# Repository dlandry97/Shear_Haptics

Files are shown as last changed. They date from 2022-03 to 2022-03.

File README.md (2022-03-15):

# Shear Haptics
The two main portions of this project include the design the mechanical structure of the device, and the integration of the haptic feedback with a virtual environment.

## How to use
1. This project uses:
    a. Unity Hub with Unity Editor run on Windows
    b. Oculus Rift with Rift Touch controllers
    c. Arduino Uno and Adafruit motorshieldv2
    d. prototype assembled with 3d printed parts(stls in models repo), servo motors, shafts, bearings, and timing belt(Links to amazon pages to non printed materials at bottom).
2. You will first need to download the arduino code from the arduino folder of the repo, and use the arduino IDE to upload it to an 'arduino uno' with a 'adafruit shieldv2'
3. You will also need the devices 

## Design
My general goal for the design was to create a shear movment about the controller grip with minimal actuators and a comfortable form as a handheld device. To achieve the linear motion of the grips, I considered many actuation schemes such as; linear actuators, worm gears, gears, belt drives. I decided to use a timing belt system actuated by a single high torque servo motor. The belt driven system gives the advantage of displacing the motor location away from the handle while still achieving strong linear force through the grips. The timing belt attaches to a set of carts guided by steel shaft rails. These shafts would function as a skeletal structure of the device as well as guide the grips in a linear path up and down the device. The second prototype increases efficiency and confort by slimming down the size of the mechanism while increasing the size of the grips.

prototypes

## Actuation
The actuation of the device is provided by a single 35kg/cm servo motor controlled by an arduino uno microcontroller. The servo drives a timing belt that attaches to and drives the grips. Each grip is designed to have a -10mm to 10mm travel range. I mounted and tested othe motor types. Using a stepper motor provided a decent amount of speed to the grip movement, but did not provide nearly enough torque to create a haptic feel. A brushed DC motor was tested and proved that it could provide torque, but did not have a sufficient ammount of speed or control for rapid testing. I added a belt gear drive to the servo system in attempt to increase its speed but keep a decent amount of torque, but the servo would stall from resistance torque from the grip.

## Interfacing
I used Unity game enigne to create a VR demo environemnt to integrate with the device. I'm using serial communication to read and write signals from Unity to the arduino to sync up to impacts in VR to the haptic feedback of the controller. I use Unity to design a VR sword that I can track the velocity data and collision status to determine the type of collision and send the appropriate status flags to the arduino to actuate the motor in the controller.

VR_Demo

### Material links
To assemble the devices, you will need the materials below or equivalent.

4mm Steel shafts: https://www.amazon.com/uxcell-Lathe-Round-Solid-Length/dp/B07KT3TT7P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

5mm shafts: https://www.amazon.com/uxcell-Stainless-Support-Fasten-Elements/dp/B07MB8QV7J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

Timing belt: https://www.amazon.com/KeeYees-Timing-Tensioner-Torsion-Printer/dp/B07JKT5BZQ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

Arduino: https://www.amazon.com/Arduino-A000066-ARDUINO-UNO-R3/dp/B008GRTSV6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

motor shield: https://www.amazon.com/Adafruit-Motor-Stepper-Shield-Arduino/dp/B00PUTH3B0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

servo shaft connector: https://www.amazon.com/Seamuing-Aluminum-Futaba-Mechanical-Helicopter/dp/B07D56FVK5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

5mm shaft connector: https://www.amazon.com/Coupling-Connector-Coupler-Accessory-Fittings/dp/B08334MFVT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

5mm bearings: https://www.amazon.com/F695-2RS-Bearing-5x13x4mm-Miniature-Bearings/dp/B07VMJLXLH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

Heat Inserts: https://www.amazon.com/F695-2RS-Bearing-5x13x4mm-Miniature-Bearings/dp/B07VMJLXLH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

Servo Motor: https://www.amazon.com/ZOSKAY-Coreless-Digital-Stainless-arduino/dp/B07S9XZYN2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

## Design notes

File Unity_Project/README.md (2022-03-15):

# Unity Project instructions
To open this project, you will need Unity Hub on Windows and an Oculus Rift Headset with the touch controllers. 
1. Download the project file and put it somewhere it can stay.
2. Open the Unity Hub and got to projects. At the top right select 'add project' and navigate to the project location.
3. Once you see the project in the Hub project menu, double click it and choose any Editior version to run it on. 
    There may be a few popups reguarding editor versions, you can chose anything.
    You may be prompted about the STEAMVR plugin and asekd to '*RESTART', Do not restart, just keep the version and select the other button.
4. The project will import and redownload all the library files that were deleted to save space for importing the project.
5. Once you get into the editor, at the bottor under 'assets', select 'My folder' and open the scene called 'This is the scene'.
6. The scene may have a few errors due to missing assets that were removed because they were purchased assets.
7. To run the demo as is, you may need an oculus rift headset and rift touch controllers for the current drivers to automatically recognise the setup.
8. You may plug in your arduino with the correct scripts already loaded. Take not of the COM port it is currently using.
9. In the scene, you may need to select the 'SerialController' object and change the 'serial COM port' to match the port of the arduino.
10. Press the 'play' button at the top of the editor to start the demo and put on your VR headset.
11. Grab the virtual Katanas and have fun with the demo.

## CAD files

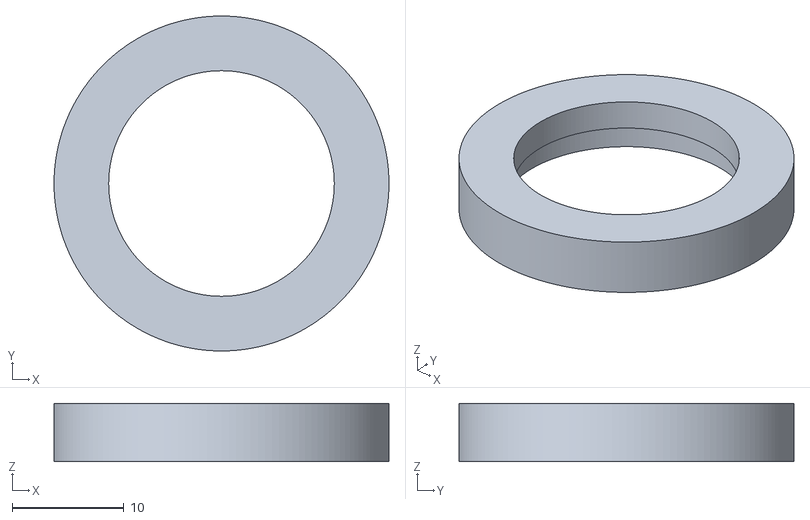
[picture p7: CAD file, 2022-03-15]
models/misc/shaft join.stl
30.0 x 30.0 x 5.20

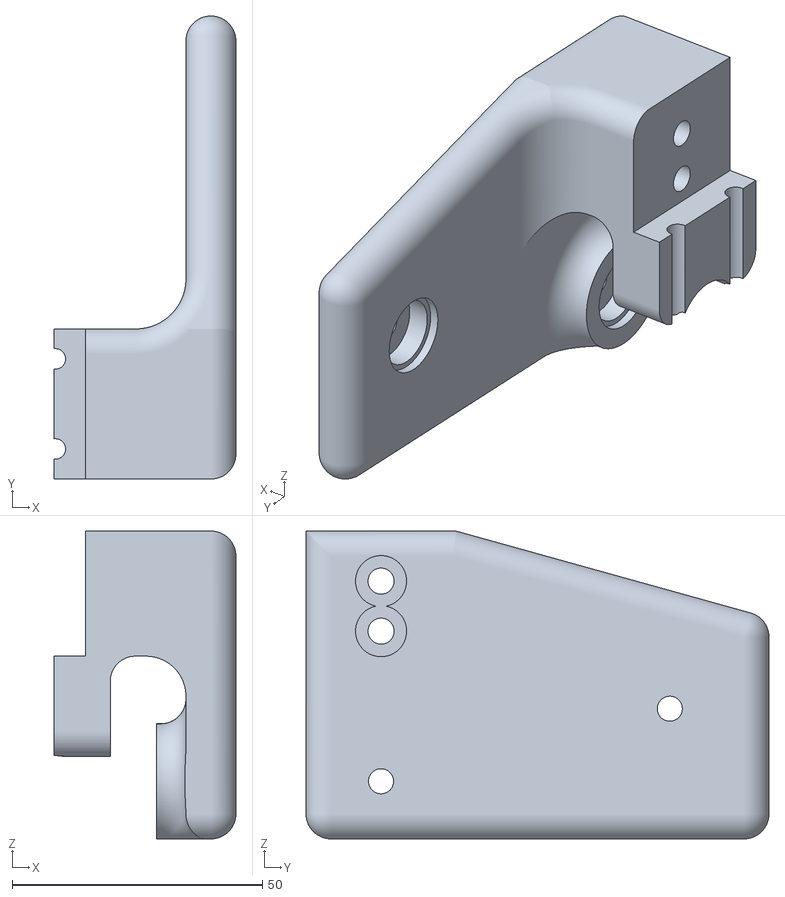
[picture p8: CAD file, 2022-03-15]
models/mk3/gearbox v4.stl
36.3 x 92.5 x 61.5

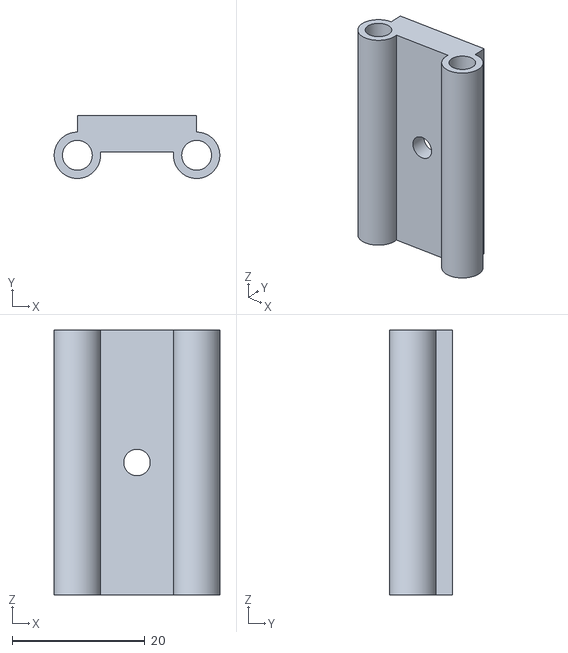
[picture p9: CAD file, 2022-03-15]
models/misc/rail_cartv3.stl
25.0 x 9.50 x 40.0

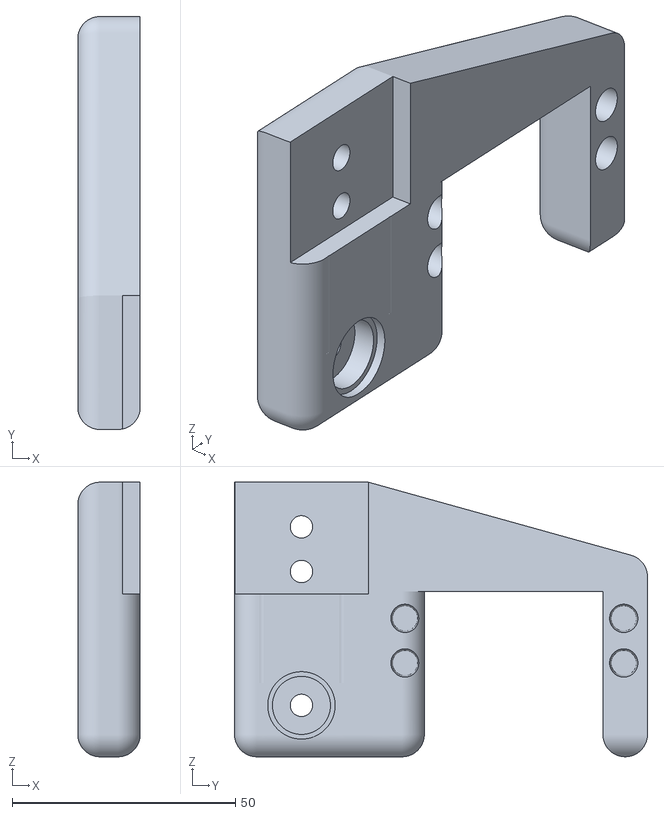
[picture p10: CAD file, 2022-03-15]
models/mk3/motor mount v4.stl
14.0 x 92.5 x 61.5

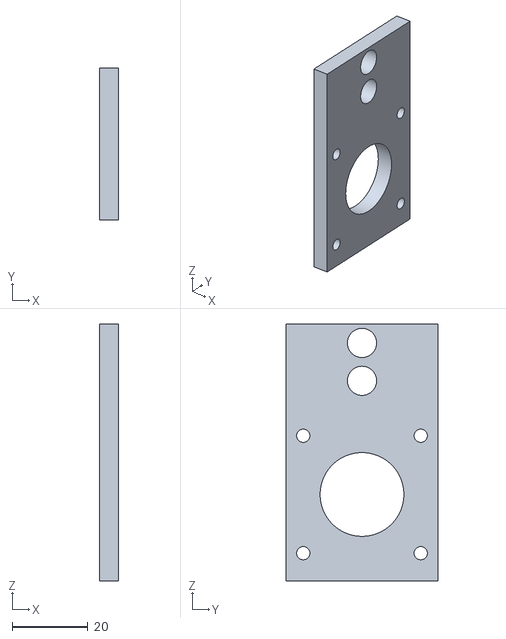
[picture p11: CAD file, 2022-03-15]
models/misc/stepper mount.stl
5.00 x 40.0 x 67.8

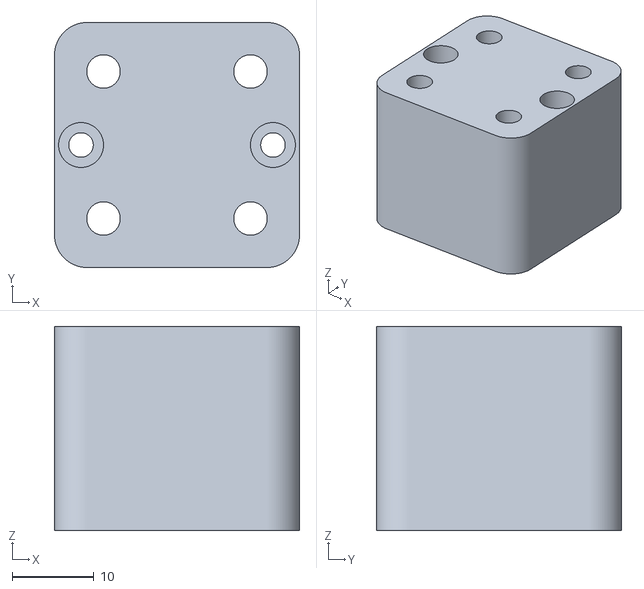
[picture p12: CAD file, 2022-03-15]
models/mk3/single top.stl
30.0 x 30.0 x 25.0

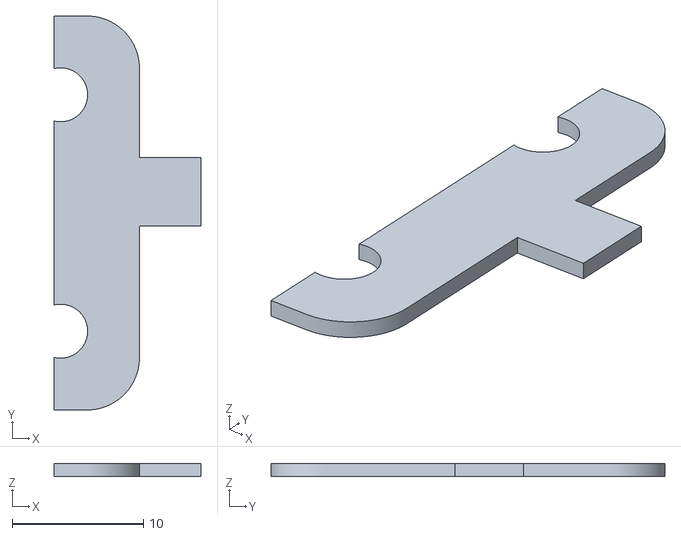
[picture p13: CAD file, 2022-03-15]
models/misc/shim.stl
11.2 x 30.0 x 1

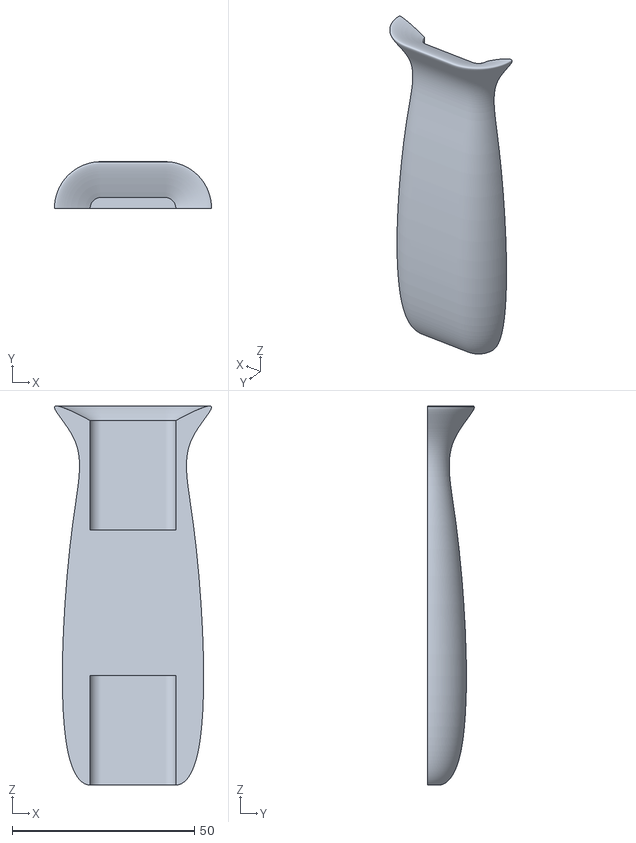
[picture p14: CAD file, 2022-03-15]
models/mk3/palm_gripv3.stl
43.1 x 12.8 x 104.0

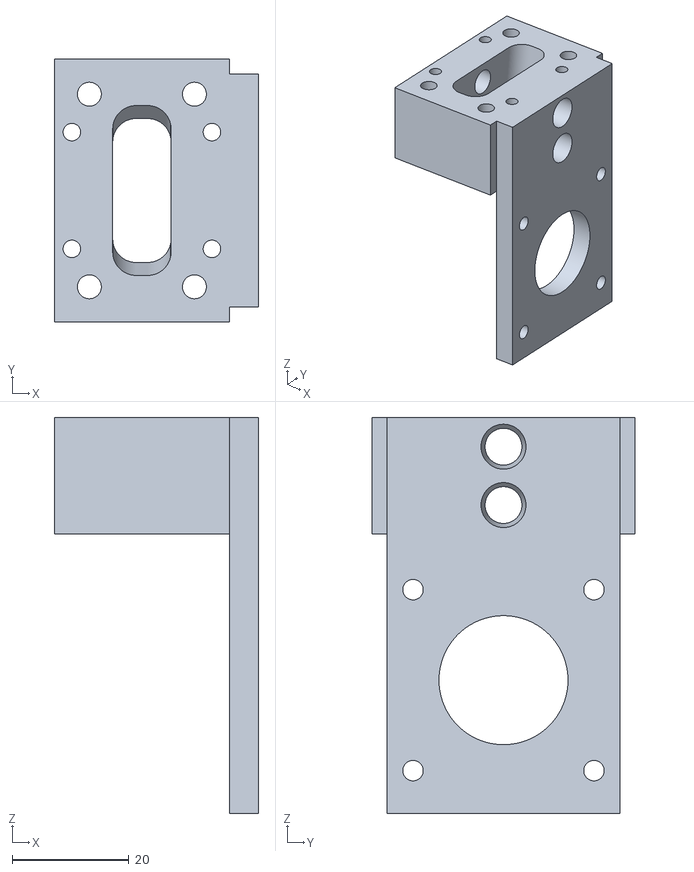
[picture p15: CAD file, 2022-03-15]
models/misc/stepper holder.stl
35.0 x 45.0 x 67.8

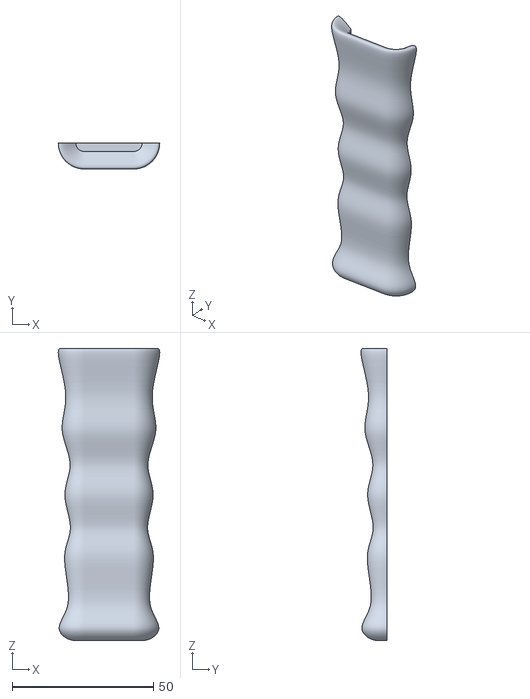
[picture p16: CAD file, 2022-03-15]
models/mk3/Finger_Gripv3.stl
35.9 x 9.22 x 103.4

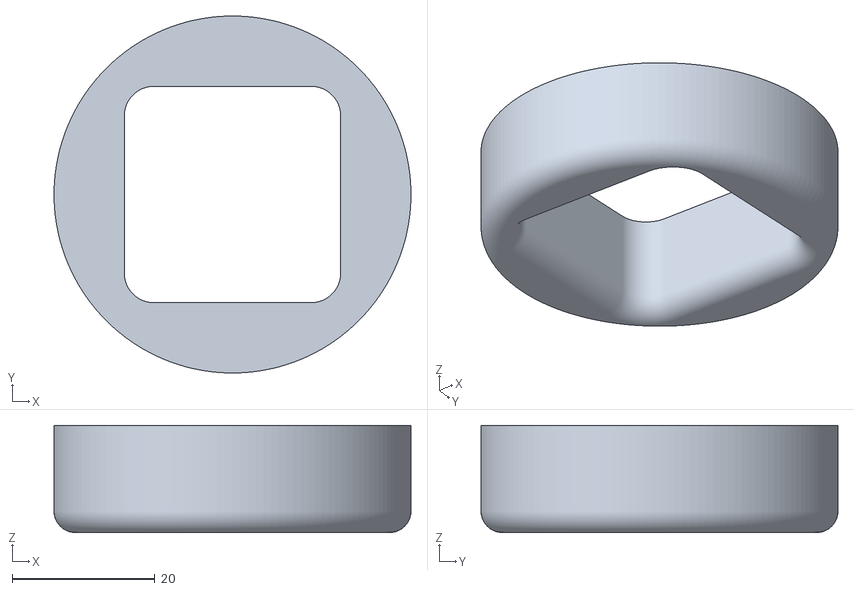
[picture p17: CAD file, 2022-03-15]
models/misc/oc adapter v3.stl
50.0 x 50.0 x 15.0

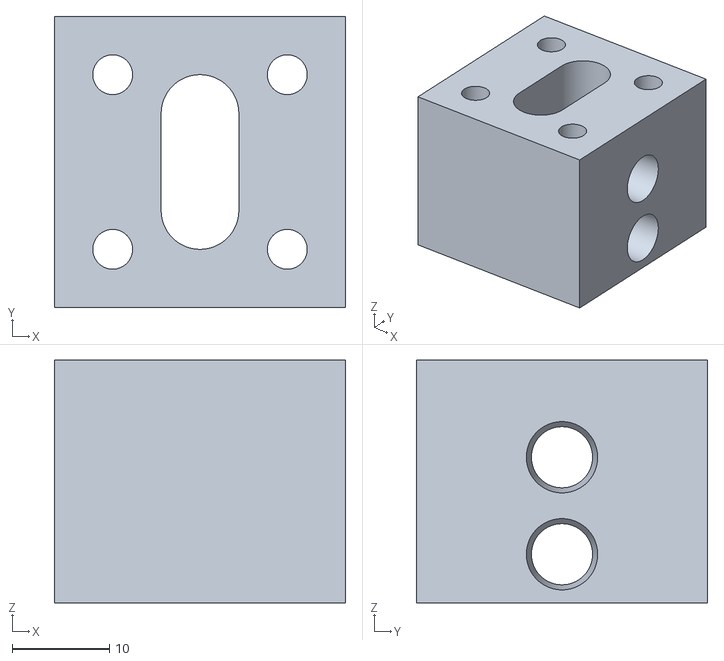
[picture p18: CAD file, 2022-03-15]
models/mk3/single_bottom.stl
30.0 x 30.0 x 25.0

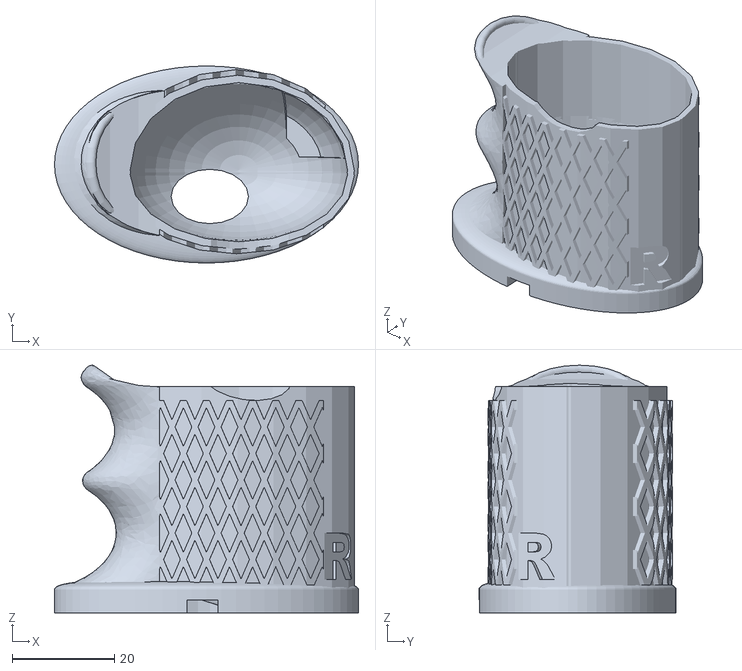
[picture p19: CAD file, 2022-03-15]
models/misc/oculus_grip_R.stl
59.4 x 38.5 x 48.4

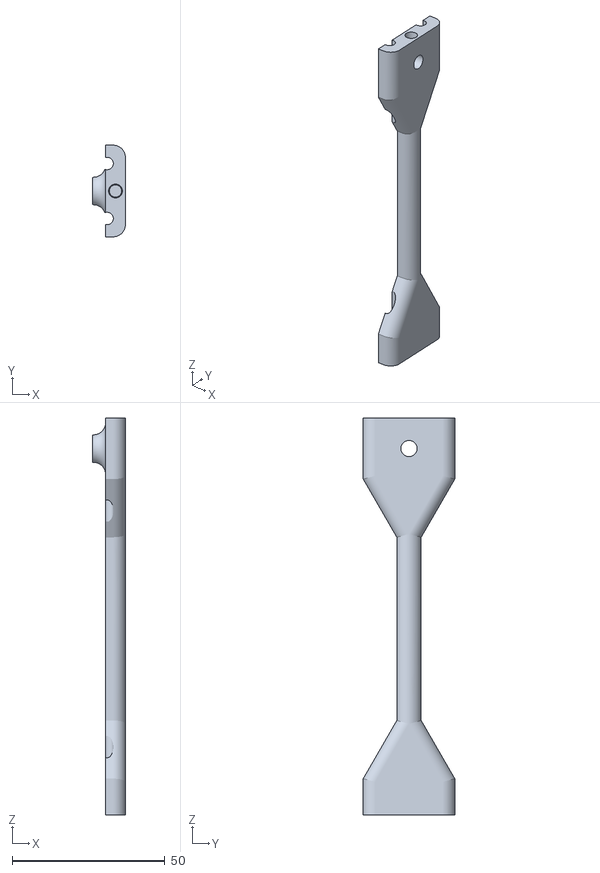
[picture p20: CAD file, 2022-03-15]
models/mk3/shorter rail guide.stl
10.8 x 30.0 x 130.0

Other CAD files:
models/mk1/Bottom cap.stl
models/mk1/Long frame.stl
models/mk1/Motor beam.stl
models/mk1/Top cap.stl
models/mk1/motor shaft support.stl
models/mk2/motor shaft support2.0.stl
models/mk2/motor_mountv2 (1).stl
models/mk2/motor_mountv2.stl
models/mk2/single_rail_guide.stl

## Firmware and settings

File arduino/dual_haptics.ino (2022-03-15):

#include <AFMotor.h>

//
//void setup() {
//  // put your setup code here, to run once:
//
//}
//
//void loop() {
//  // put your main code here, to run repeatedly:
//
//}

#include <Servo.h>

Servo myservo;  // create servo object to control a servo
// twelve servo objects can be created on most boards

int pos = 0;    // variable to store the servo position
int del = 0;

void setup() {
  Serial.begin(9600);
  myservo.attach(10);  // attaches the servo on pin 9 to the servo object
}
void loop() {
//  Serial.print("\n in loop");
  del=700;
  myservo.write(90);
  delay(del);



  myservo.write(130);
  delay(del);
//
//  myservo.write(60);
//  delay(del);
//
//
//
//  myservo.write(35);
//  delay(del);
  
  
//  char msg;
//  pos = 0;
//  del=700;
////  myservo.write(60);
////  delay(del);
//  if(Serial.available()){
////    Serial.print("\n Serial is avail");
//    msg = Serial.read();
////    Serial.print(msg);
//  }
//  
//  
//  
//  if (msg == 'A'){
//    myservo.write(70);
////    Serial.print("\n geting 70");
//    delay(del);
//  }
//  if (msg == 'Z'){
//    myservo.write(90);
////    Serial.print("\n geting 50");
////    delay(del);
//  }
//  if (msg == 'B'){
//    myservo.write(60);
////    Serial.print("\n geting 60");
//    delay(del);
//  }
}
